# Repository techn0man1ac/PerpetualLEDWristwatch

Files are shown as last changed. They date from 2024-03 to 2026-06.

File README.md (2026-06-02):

UA_version_README
GB_version_README (https://github.com/techn0man1ac/PerpetualLEDWristwatch)

# 12 LED ATtiny "Perpetual" Wristwatch

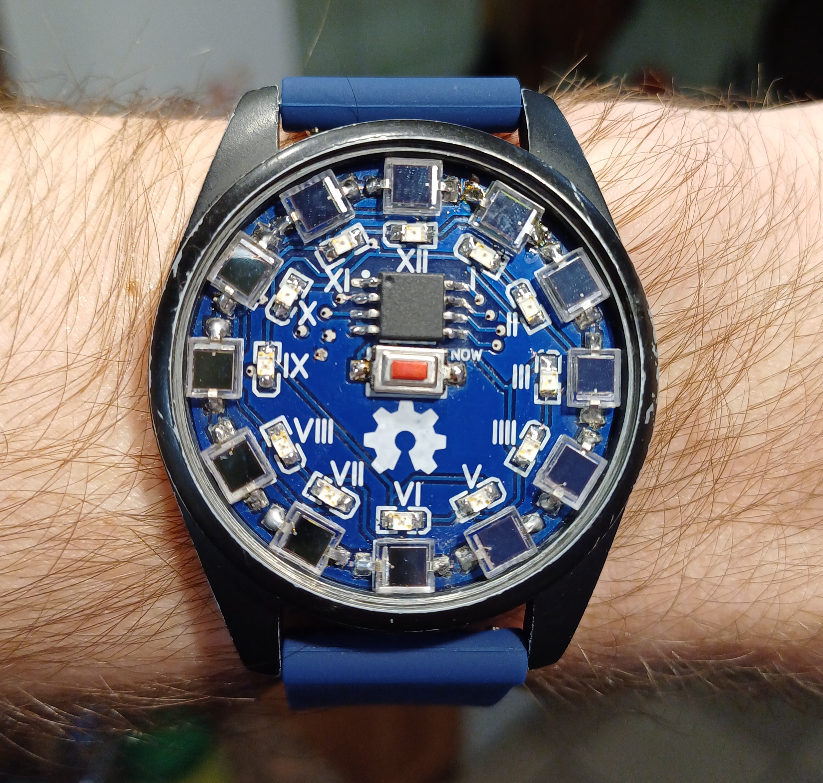
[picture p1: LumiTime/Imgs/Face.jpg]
Device_face


The simple and "Perpetual" WristWatch(project code name "LumiTime") with 12 red LEDs, it have LIR2430 Li-Ion battery and 12 solar cells, based on a simple Microchip microcontroller ATtiny13. It full open source(firmware and hardware).

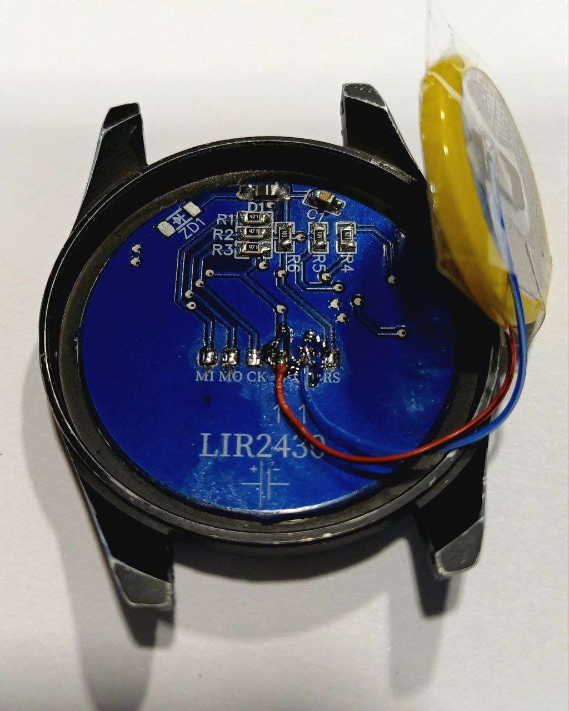
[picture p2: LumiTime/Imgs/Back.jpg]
PCB_back


# Video demonstration:

https://youtu.be/T3b3lKKN2u0

# How it's work?

Every 0.5 seconds, the processor wakes up (cycle iteration time is 100 microseconds), increments the millisecond variable, and quickly goes to sleep, the whole process consumes 3 to 5 µA:

https://youtu.be/rdMVb2fhGco

The wristwatch has a "NOW" button and 12 LEDs, if you press the button, the time is displayed on the LEDs according to the following algorithm - first the hours are displayed (1, 2, 3, 4, 5, 6, etc. ) and then the minutes are shown in step 5 minute(5, 10, 15, 20, 25, 30, and so on...), but the LED blinks as many times as you need to add to this number to get the time. 
For example, it is now 48 minutes, the LED 45 will light up and blink 3 times, that is, 45+3=48. Then CPU go back to sleep.

# How to set the time?

https://www.youtube.com/shorts/7TG0KjUsHnk

If you press the button and hold it, after 10 seconds the watch will start shifting the time by 5 minutes each display cycle, and this will continue until you release the button.

# 3D model PCB:

PCB face side:

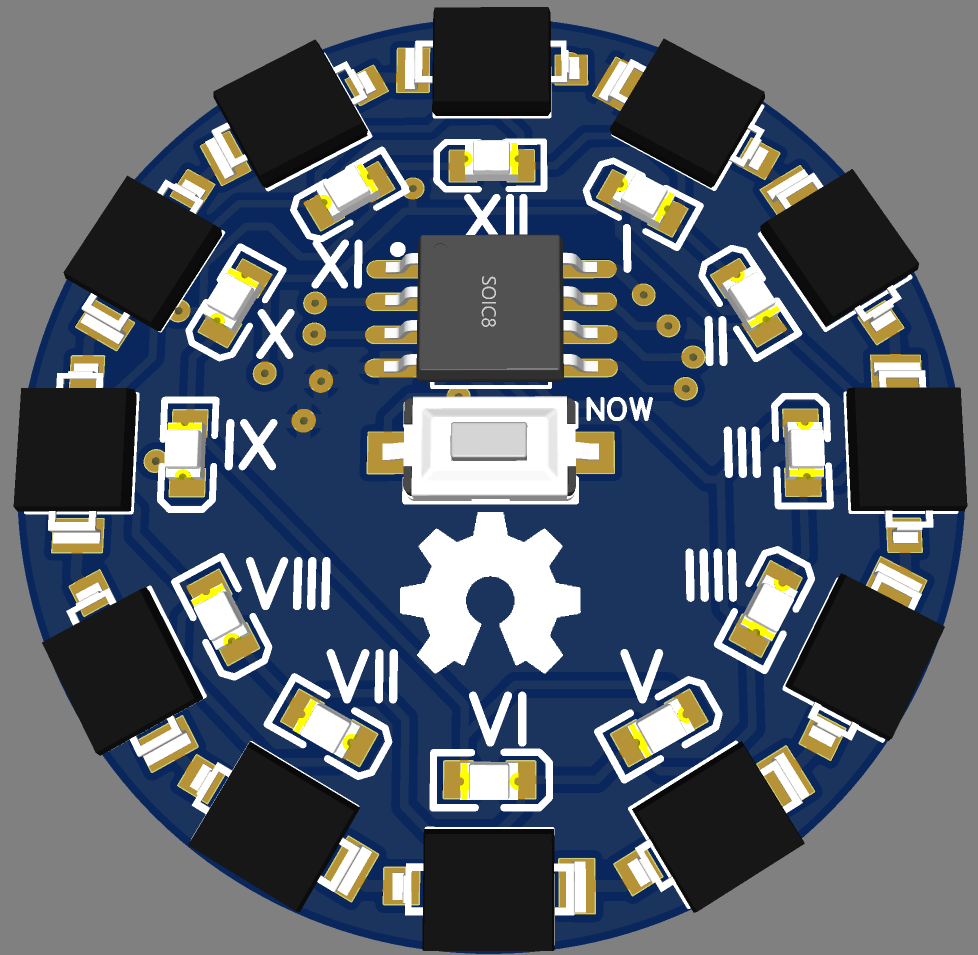
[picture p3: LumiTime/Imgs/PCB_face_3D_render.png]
PCB_Up_3D_Render


PCB back side:

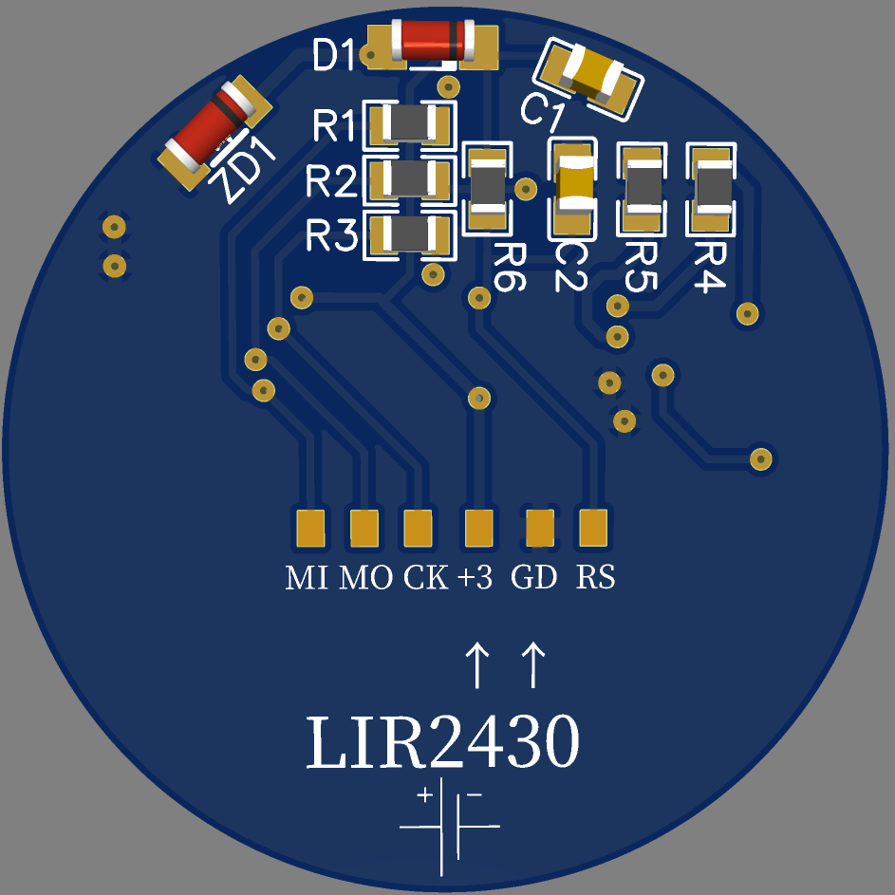
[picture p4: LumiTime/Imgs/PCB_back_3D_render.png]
PCB_Down_side_3D_Render


PCB have size 35 mm in the diameter:

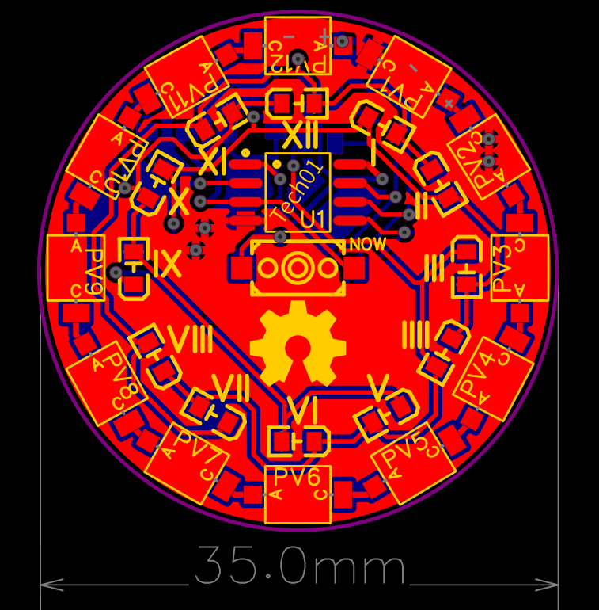
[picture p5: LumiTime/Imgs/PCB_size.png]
PCB_size


The thickness of the board is recommended to take 0.8mm otherwise it may not fit into the case.

# Gerber files and 3D model:

Files for fabrication:

https://github.com/techn0man1ac/PerpetualLEDWristwatch/tree/main/LumiTime/PCB

# PCB home page:

Fresh board project here:

https://oshwlab.com/raznie.podelki/attiny85binarywatches_copy

You can order a prototype for testing here(completely ready device without firmware):

https://www.pcbway.com/project/shareproject/_Perpetual_Wristwatch_d14e5fc4.html

# Schematic:

It's have simple schematic, for save pins I used Charlieplexing(35 components in total):

https://en.wikipedia.org/wiki/Charlieplexing

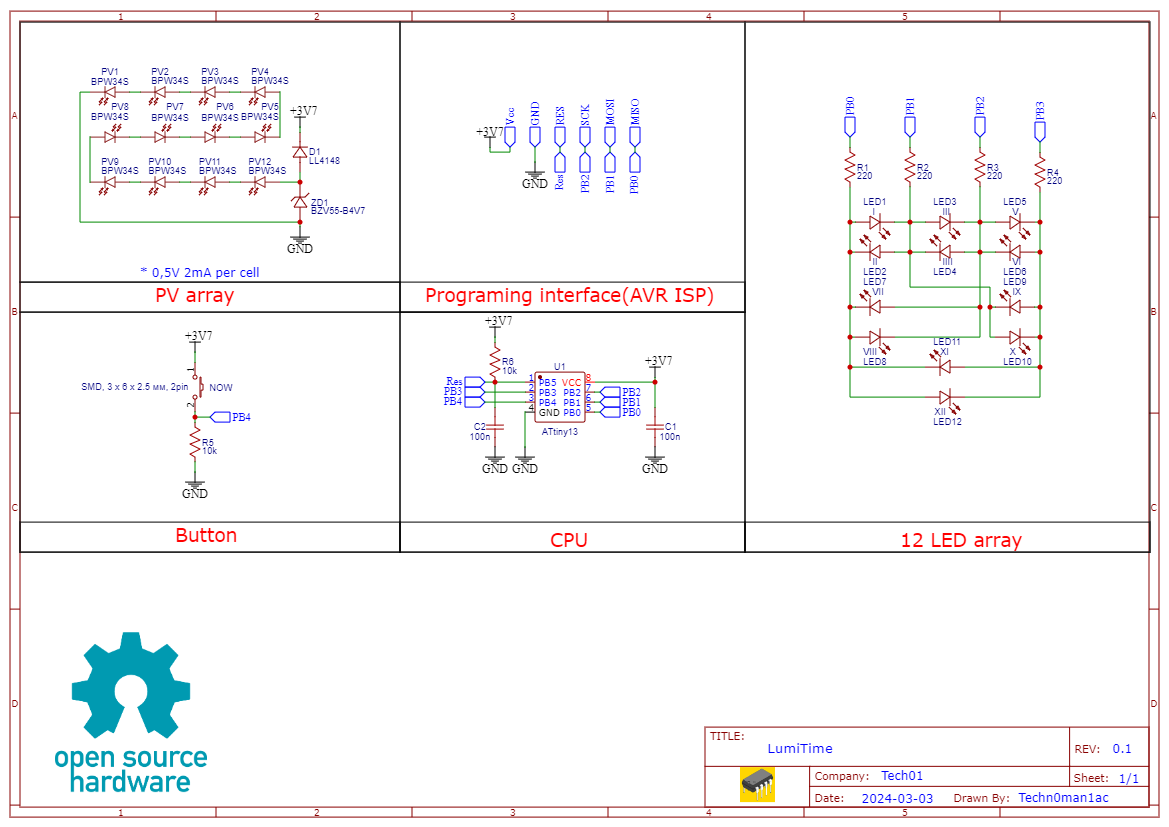
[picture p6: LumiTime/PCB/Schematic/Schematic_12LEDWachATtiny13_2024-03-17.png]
Schematic_Wristwatch


In this project i use for charging 12 light sensor BPW34S(PV array), on clear sun one cell make 0.5-0.6 V and ~2 mA, connect its in serial and make simply charging schematic - use 2 components, ZD1 to drop voltage 6 -> 4.7 V and make protection to leakage of current in solar panels in to diode D1 name LL4148(because it have little reverse current):

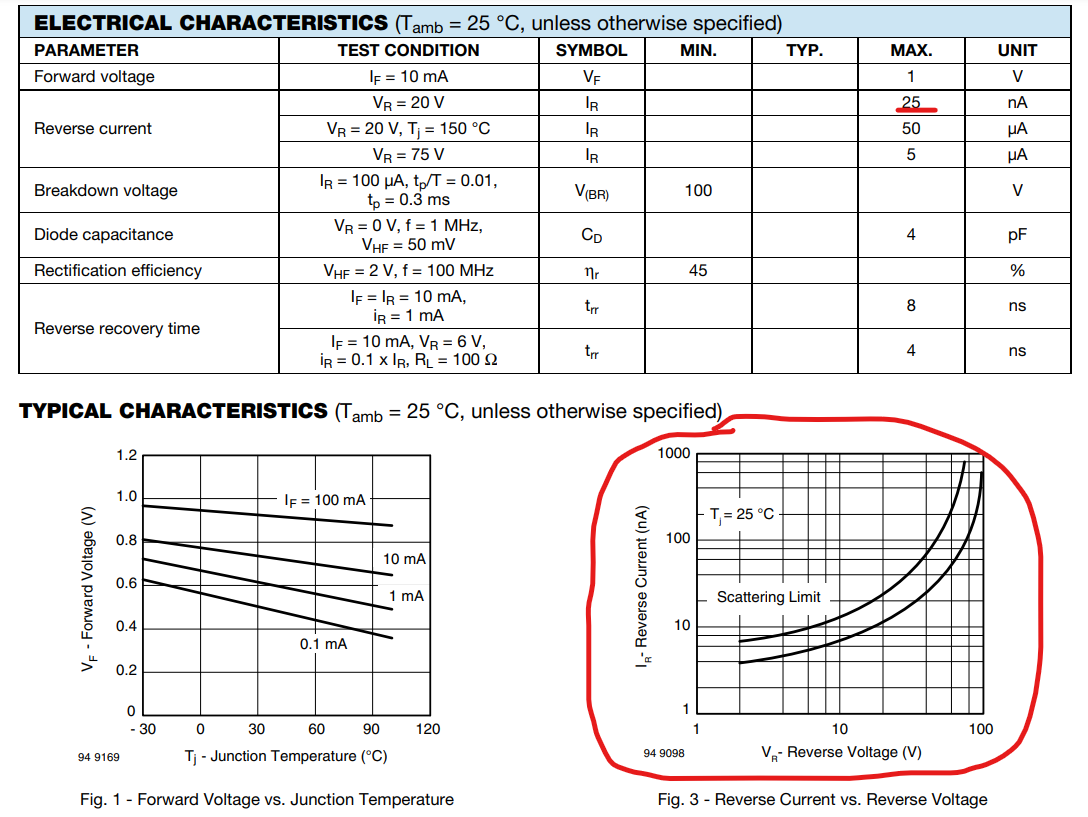
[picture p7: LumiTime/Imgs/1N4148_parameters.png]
1N4148_parameters


The diode add 0.7 volts drop(4.7-0.7=4.0V) and battery don't overcharge up to 4 V.

# How to flash ATtiny

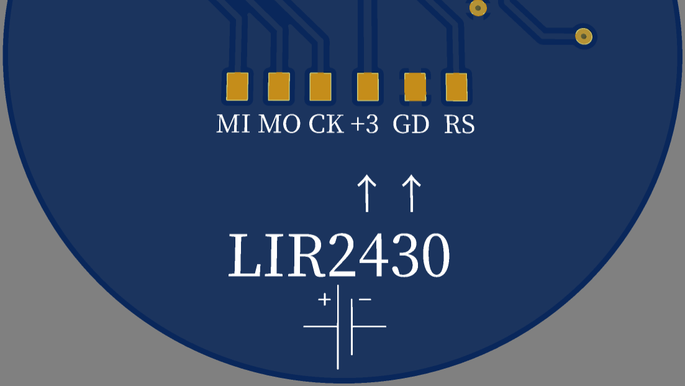
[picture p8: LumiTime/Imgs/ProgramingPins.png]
AVR ISP programmer pinout


Here is pinout for AVR ISP programmer - unsolder battery and power up 3V pins to programmer 5V, MI->MISO programer(Arduino digital Pin 11), MO->MOSI(digital Pin 12), CK->SCK(digital Pin 13) RS->Reset(digital Pin 10) and GD-> programmer GND. 

How to flash ATtiny13 with Arduino:

https://www.hackster.io/taunoerik/programming-attiny13-with-arduino-uno-07beba

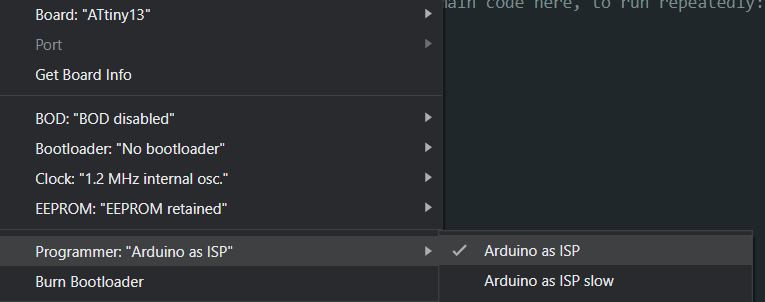
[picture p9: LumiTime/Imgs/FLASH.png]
FLASH


ATtiny13 core selections:

- Board: ATtiny 13

- BOD: BOD Disabled

- Clock: 1.2 MHz internal osc.

- Compiler LTO: Enable

- Port: (Your Arduino port)

- Programmer: Arduino as ISP

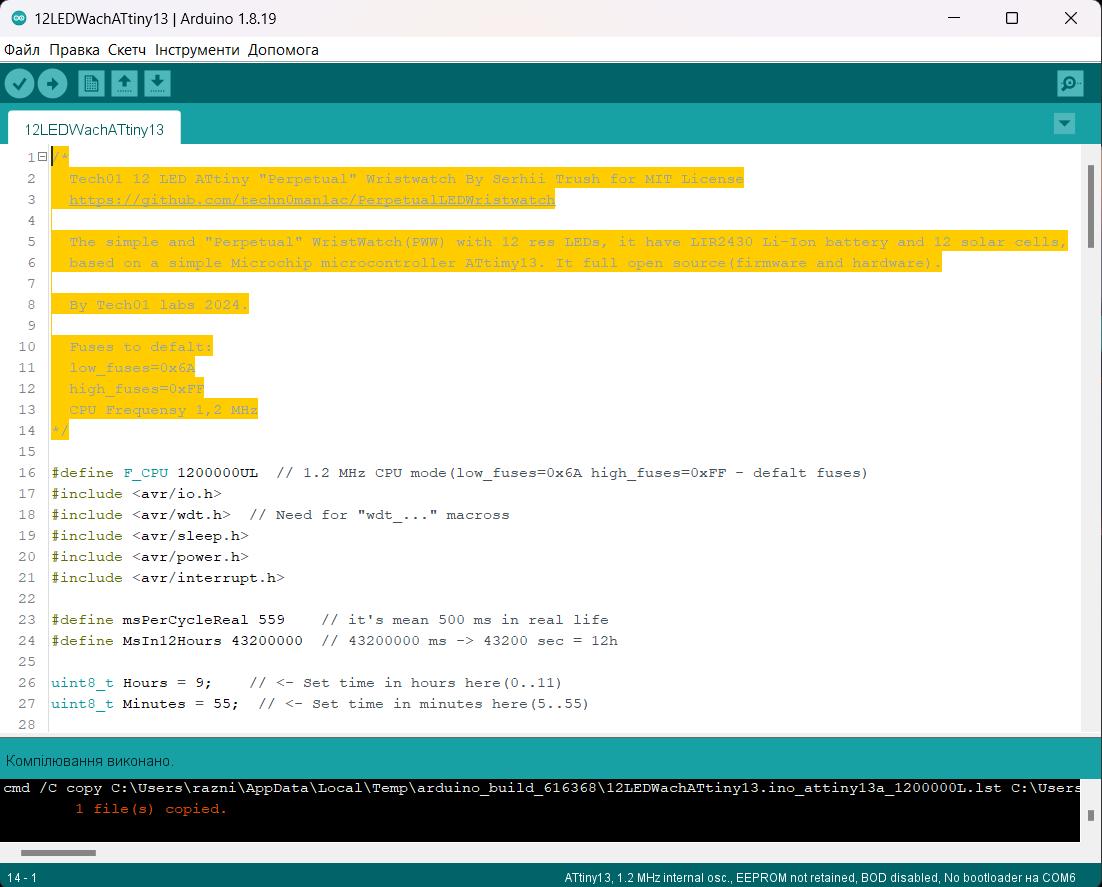
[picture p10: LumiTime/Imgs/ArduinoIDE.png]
Arduino IDE


Source code(for Arduino IDE - "12LEDWachATtiny13.ino") here:

https://github.com/techn0man1ac/PerpetualLEDWristwatch/tree/main/LumiTime/Code/12LEDWachATtiny13

The default time, which start the clock, set in the code, these are the 27 and 28 code lines.

This project full open source(PCB and code), so anyone can modernize it. But we must give credit to the previous project, without which there would be no "ATtiny13BinaryWatches":

https://github.com/techn0man1ac/ATtiny13BinaryWatches

# Power consumption

In standby mode (when the button is not pressed), the wristwatch consumes approximately 5 μA, the battery have capacity - 50 mAh, in time show mode watch consumes 2.5 mA, if you look at the time every day 6 times(0.25 per hour), the operating time is 1.5 seconds, using these data we can calculate battery life time. For example - calculator from Oregon Embedded:

https://oregonembedded.com/batterycalc.htm

We have ~year of work, of course, as the voltage drops, the consumption of the watch will also drop (for example - 2.7 V, the consumption is ~3 μA), therefore, the resulting lower value is the guaranteed uptime:

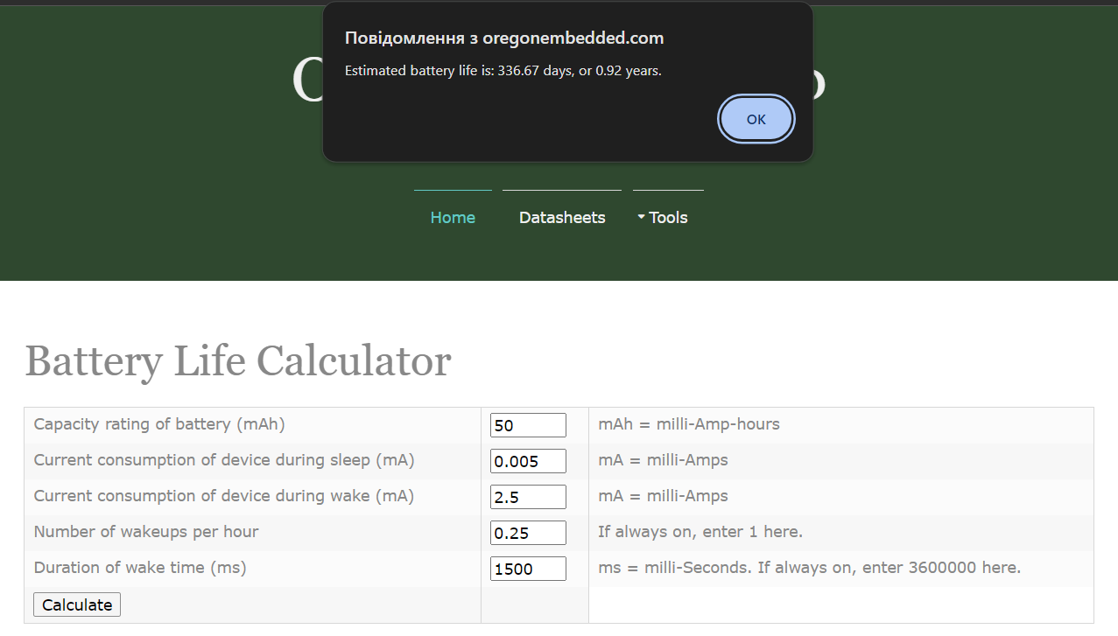
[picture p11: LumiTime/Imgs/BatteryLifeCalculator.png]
BatteryLifeCalculator


However, if you give the device 5-10 minutes a day of street light (for example, take it out of your sleeve), and the working time will immediately increase several times. Here in the video I show how the watch charges even in cloudy weather:

https://youtu.be/5vcrXjH7wVM

It is worth noting that LED bulbs, which are now very popular for indoor lighting, do not provide a sufficient level of light in the spectrum at which solar panels work, so charging is possible only very close LED lamp.

# Case

You can find the case files here:

https://github.com/techn0man1ac/PerpetualLEDWristwatch/tree/main/LumiTime/Case

Please note that the project is still under development and is subject to change.

# Our mission and vision

Mission:

"To develop a simply and eco-friendly watch that integrates innovative technologies with minimal components, ensuring energy efficiency is within reach for all.".

Vision:

"We aim to achieve a world where energy-saving technology is accessible to everyone, where our watch serves as a symbol of environmental stewardship and innovative solutions in energy efficiency."

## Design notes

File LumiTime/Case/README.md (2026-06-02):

Design based the case on a watch similar to my project:

https://www.thingiverse.com/thing:4037268

The only difference is that theirs has two buttons, while mine has just one.

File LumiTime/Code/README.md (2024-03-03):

  By Tech01 labs 2024.

  Fuses to defalt:
  
  low_fuses=0x6A
  
  high_fuses=0xFF
  
  CPU Frequensy 1,2 MHz

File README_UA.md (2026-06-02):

UA_version_README
GB_version_README (https://github.com/techn0man1ac/PerpetualLEDWristwatch)

# "Вічний" наручний годиник на 12-ти світлодіодах

Device_face

Простий та "вічний" наручний годиник з 12-ма світлодіодами(кодове ім'я проєкту "LumiTime"), має LIR2430 Li-Ion батарею та 12 мікро сонячних панелей, оснований на простому мікроконтролері від Microchip ATtiny13. Цей проєкт повністю open source(залізо та прошивка).

PCB_back

# Відео з демонстрацією:

https://youtu.be/T3b3lKKN2u0

# Як це працює?

Кожні 0.5 секунди процесор прокидається(час ітерації циклу 100 мікросекунд), інкрементує змінну мілісекунд, та швиденько засипає, весь цей процес забирає споживання від 3 до 5 мкА:

https://youtu.be/rdMVb2fhGco

Наручний годиник має кнопку "NOW" та 12 світлодіодів, якщо натиснути кнопку - показується час на світлодіодах згідно з наступним алгоритмом - спочатку показуються години(1, 2, 3, 4, 5, 6 і так далі...) і потім показуються хвилини з кроком в 5 хв(5, 10, 15, 20, 25, 30 і так далі...), але світлодіод блимає стількм разів, скільки треба додати до цього числа щоб отримати час, наприклад зараз 48 хвилин, загориться світлодіод 45 і проблимає 3 рази, тобто 45+3=48. Далі -> знову сон.

# Як виставити час?

https://www.youtube.com/shorts/7TG0KjUsHnk

Якщо натиснути кнопку і тримати її на протязі 10 секунд, час почне збільшуватись на 5 хв кожен цикл відображення доти, допоки кнопка не відпуститься.

# 3D рендер плати:

Лицьова сторона плати:

PCB_Up_3D_Render

Зворотня сторона плати:

PCB_Down_side_3D_Render

Плата має 35 мм в діаметрі:

PCB_size

Товщина плати має бути 0.8 мм, інакше просто не поміститься в корпус.

# Gerber файли та 3D модель:

Файли для виготовлення:

https://github.com/techn0man1ac/PerpetualLEDWristwatch/tree/main/LumiTime/PCB

# Сторінка плати:

Свіжа версія плати завжди тут:

https://oshwlab.com/raznie.podelki/attiny85binarywatches_copy

Замовити прототип для тестування можна ось тут(закінчений пристрій але без прошивки):

https://www.pcbway.com/project/shareproject/_Perpetual_Wristwatch_d14e5fc4.html

# Схемотехніка:

Пристрій має просту схемотехніку, для економії виходів мікроконтролера я використав Мультиплексування методом Чарлі(сумарно 35 компонентів):

https://en.wikipedia.org/wiki/Charlieplexing

Schematic_Wristwatch

В цьому проєкті, для заряджання, я використав 12 фотодіодів BPW34S(PV array), у сонячну погоду один елемент генерує 0.5-0.6 В і ~2 мА, з'єднав їх послідовно та зробив просту зарядну схему використовуючи 2 компоненти - стабілітрон ZD1 знижує напругу з 6 до 4.7 В та наявний захист від "витоку" струму в сонячні панелі з допомогою діоду D1 LL4148(саме цей має низький зворотній струм):

1N4148_parameters

Діод добавляє падіння напруги в 0.7(4.7-0.7=4.0 В), відповідно, акумулятор не перезарядиться більше 4 В.

# Як запрограмувати мікроконтролер ATtiny

AVR ISP programmer pinout

Ось розпіновка для підключення до AVR ISP програматора - відпаяйте батарею і запаяйте на ніжку 3V 5 Вольт з програматора, MI->MISO програматора(Arduino пін 11), MO->MOSI(пін 12), CK->SCK(пін 13) RS->Reset(пін 10) та GD-> земля програматора(GND).

Як запрограмувати ATtiny13 використовуючи Arduino:

https://www-hackster-io.translate.goog/taunoerik/programming-attiny13-with-arduino-uno-07beba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

FLASH

Параметри для ATtiny13:

- Плата: ATtiny 13

- BOD: BOD Disabled

- Частота: 1.2 MHz internal osc.

- Compiler LTO: Enable

- Порт: (Ваш Arduino порт)

- Програматор: Arduino as ISP

Arduino IDE

Вихідний код(для Arduino IDE - "12LEDWachATtiny13.ino") ось тут:

https://github.com/techn0man1ac/PerpetualLEDWristwatch/tree/main/LumiTime/Code/12LEDWachATtiny13

Час по замовчуванню, з якого стартує годинник задається в коді, це 27 та 28 стрічки.

Цей проєкт є повністю відкритим, як плата так і прошивка для мікроконтролера, тому його модернізувати може кожен. Але треба віддати належне попередньому проєкту, без якого цього б не існувало "Бінарний наручний годиник":

https://github.com/techn0man1ac/ATtiny13BinaryWatches

# Енергоспоживання

В режимі очікування(коли кнопка не натиснена) годинник споживає приблизно 5 мкА, ємність акумулятора 50 мА*год, під час роботи годинник споживає 2.5 мА, якщо дивитись час 6 разів на добу(0.25 разів на годину) час роботи 1.5 секунди, використовуючи ці дані можна порахувати на скільки вистачить батареї. Наприклад - калькулятором від Oregon Embedded:

https://oregonembedded.com/batterycalc.htm

Маємо майже рік роботи, звісно з падінням напруги буде падати і споживання годинника(при 2.7 В споживання вже 3 мкА), тому отримане нище значення, це гарантований час роботи:

BatteryLifeCalculator

Проте, варто лиш 5-10 хвилин на день потримати девайс на вуличному світлі(наприклад дістати його з рукава), і відразу термін роботи збильшиться в рази, ось на відео показую, як годинник заряджається навіть у похмуру погоду:

https://youtu.be/5vcrXjH7wVM

Варто зауважити, що світлодіодні лампочки, котрі зараз дуже популярні для кімнатного освітлення не дають достатній рівень світла в спектрі, при якому працюють сонячні панелі, тому зарядка можлива лиш в притул до LED лампи.

# Корпус

Файли корпусу можна знайти за посиланням:

https://github.com/techn0man1ac/PerpetualLEDWristwatch/tree/main/LumiTime/Case

Зверніть увагу, що проект ще перебуває на стадії розробки і може зазнавати змін.

# Місія та візія проєкту

Місія:

"Розробити простий і екологічно чистий годинник, який поєднує в собі інноваційні технології з мінімальною кількістю компонентів, гарантуючи, що енергоефективність доступна для всіх.".

Візія:

"Ми прагнемо створити світ, де енергозберігаючі технології будуть доступні кожному, де наш годинник буде символом піклування про навколишнє середовище та інноваційних рішень у сфері енергоефективності."

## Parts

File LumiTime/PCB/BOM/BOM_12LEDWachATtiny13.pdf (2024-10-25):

ID | Name | Designator | Footprint | Quantity | Manufacturer Part
1 100n | | C1,C2 | C0805 | 2 50V 100nF X7R ±10% 0805 Multilayer Ceramic Capacitors
2 LL4148 | | D1 | LL-34_L3.4-W1.5-RD | 1 LL4148 SOD80
3 LED1-LED12 | | I-XII | LED0805-RD_RED | 12 SMD Red LED 0805
4 SMD, 3 x 6 x 2.5 мм, 2pin | | NOW | KEY-SMD_2P-L6.2-W3.6-LS | 1 SMD, 3 x 6 x 2.5 мм, 2pin
5 BPW34S | | PV1,PV2,PV3,PV4,PV5,PV6,PV7,PV8,PV9,PV10,PV11,PV12SENSOR-TH_BPW34S-Z | | 12 BPW34S-Z
6 220 | | R1,R2,R3,R4 | R0805 | 4 ±5% 220Ω 0805 Chip Resistor
7 10k | | R5,R6 | R0805 | 2 ±5% 10kΩ 0805 Chip Resistor
8 ATtiny13 | | U1 | SOIC-8_L5.3-W5.3-P1.27-L | 1 ATTINY13A-SU
9 BZV55-B4V7 | | ZD1 | LL-34_L3.5-W1.5-RD | 1 BZV55-B4V7 SOD80

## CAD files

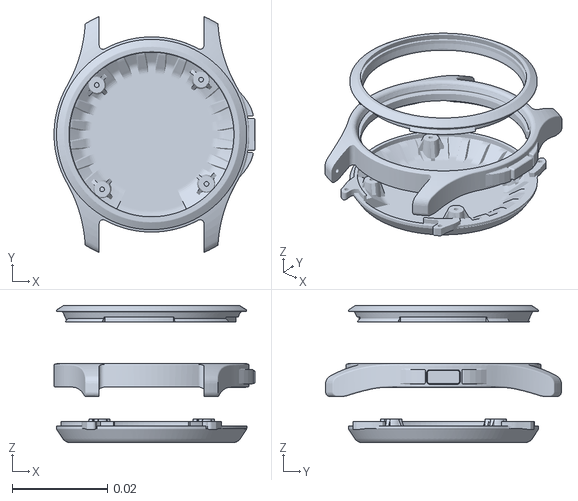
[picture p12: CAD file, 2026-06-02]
LumiTime/Case/Watch.stl
0.0422 x 0.0496 x 0.0289

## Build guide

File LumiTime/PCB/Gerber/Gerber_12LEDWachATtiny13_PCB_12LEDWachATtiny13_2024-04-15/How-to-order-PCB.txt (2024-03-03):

How to Order PCB

Please refer to:
https://docs.easyeda.com/en/PCB/Order-PCB

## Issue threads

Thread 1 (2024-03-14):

case?

alwaysmohawk, 2024-03-14:
Hi, cool project, found it on hackaday.

I didn't see any information on the case you used. Is it possible to share the source of your watch case, or give some tips on how to find a suitable case?

Thanks,

techn0man1ac, 2024-03-14:
Hi, thank's. I use case from old China wristwatch.
I still don't know how to do 3D modeling, so I didn't design the case, but used an already ready one.
Yes, I am open to all advice from your side

techn0man1ac, 2024-03-16:
> ...or give some tips on how to find a suitable case?

PCB have size 35 mm in the diameter,  search for cases from an old watch where the dial is 35 mm in diameter
The thickness of the PCB is recommended to take 0.8mm, because it will be very tight in the case with the battery.

voloved, 2024-11-04:
>  I use case from old China wristwatch

Do you know the exact model you used?

techn0man1ac, 2024-11-08:
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
No name brand

Closed 2025-01-16.

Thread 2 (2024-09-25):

Setting Time

edoxxx, 2024-09-25:
hello, very interesting project but would it be possible to develop the code to reset the hour and minutes by taking advantage of the button? because putting back the time would mean having a computer.

let me know.

techn0man1ac, 2024-10-12:
Hi @edoxxx yes, it's [done](https://github.com/techn0man1ac/PerpetualLEDWristwatch/commit/85db25f01018a77f09de6c6412757746059755f4).

Thank you for your request, at the moment I have reset the clock to the initial time if you press the button for more than 10 seconds.

You can test and provide feedback here.

techn0man1ac, 2024-10-17:
@edoxxx Yes, you can take a more advanced model - ATtiny85 where there is 8 times more flash memory. However, I plan to add  for ATtiny13 a time task (if you hold the button for more than 10 seconds, then the time will change every 1 second of holding the button up to 5 minutes) and so on until you release the button.

A watch case would be great, if you need some dimensions - write, I will measure everything.

edoxxx, 2024-10-17:
Wow if you could write this code, it would be great.

I was trying to create a code where the prolonged pressure takes you to the "hour menu" where with the single click you go on with the hours then you hold down for a long time and you go to the menu of minutes then you go back to the original operation.

But in my code there are too many variables to intercept the prolonged and single pressures that don't work well and if I try to add more code to fix I don't have any more space in the micro. 😂😮‍💨

techn0man1ac, 2024-10-18:
@edoxxx  I added a time setting (minutes) if you press and hold the button for more than 10 seconds, then the time will be added by 5 minutes per display cycle as long as the button is held.

techn0man1ac, 2024-10-19:
https://www.youtube.com/shorts/7TG0KjUsHnk

techn0man1ac, 2024-10-19:
https://www.youtube.com/shorts/7TG0KjUsHnk

edoxxx, 2024-10-19:
This is really amazing.
Now I think it's a really complete project.
Thank you very much!!

techn0man1ac, 2024-10-19:
Thank you @edoxxx

New feature and new bugs 🐞 🙂

It's just beginning, so a lot of work ahead 🚀

Closed 2024-10-22.

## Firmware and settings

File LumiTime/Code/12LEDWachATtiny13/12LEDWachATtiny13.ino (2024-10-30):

/*
  Tech01 12 LED ATtiny "Perpetual" Wristwatch By Serhii Trush with MIT License.
  https://github.com/techn0man1ac/PerpetualLEDWristwatch

  The simple and "Perpetual" WristWatch(project code name "LumiTime") with 12 red LEDs, it has LIR2430 Li-Ion battery and 12 solar cells,
  based on a simple Microchip microcontroller ATtiny13. It is fully open source (firmware and hardware).

  Sketch uses 1008 bytes (98%) of program storage space. Maximum is 1024 bytes.
  Global variables use 13 bytes (20%) of dynamic memory, leaving 51 bytes for local variables. Maximum is 64 bytes.

  By Tech01 labs 2024.
*/

#define F_CPU 1200000UL  // CPU frequency set to 1.2 MHz mode(low_fuses=0x6A high_fuses=0xFF - defalt fuses)
#include <avr/io.h>      // AVR I/O library for ATtiny13
#include <avr/wdt.h>     // Watchdog Timer library
#include <avr/sleep.h>   // Sleep mode library
#include <avr/power.h>   // Power management library
#include <avr/interrupt.h>  // Interrupt library

// Constants for time calculations
#define msPerCycleReal 560    // Real cycle duration in milliseconds (approximately 500ms)
#define MsIn12Hours 43200000  // Total milliseconds in 12 hours
#define ButtonPin PINB4       // PB4 is the button pin
#define TimeSetDalay 40       // TimeSetDalay / 4 = how many seconds need press the button to time set mode

// Global variables to store time and mode states
uint8_t Hours = 9;            // Default hour setting (0..11)
uint8_t Minutes = 18;         // Default minute setting (5..55)
volatile uint8_t InterruptWDT = 0; // Watchdog timer interrupt flag
volatile uint32_t MilliSeconds = 0;   // Milliseconds since the start of the current cycle
uint8_t FiveMinutesDiscrete = 0;  // Discretized minutes in steps of five (5,10..55)
uint8_t MinutesRemainder = 0;   // Remaining minutes after discretization (0..4)
uint8_t MinutesOnLED = 0;     // LED index for displaying time
uint8_t Mode = 0;             // Current mode state
uint8_t NextMode = 0;         // Next mode to transition into
uint8_t ButtonPressCount = 0; // Count of button presses

// Function prototypes for readability and organization
void initHardware();
uint8_t ButtonPress();        // Check if the button is pressed
uint8_t ShowTime(uint8_t);    // Display time on LEDs based on current mode
void ledOn(uint8_t);          // Turn on a specific LED (not used in this code)
void Up5Minutes();            // Increment time by 5 minutes
void TimeToMs();              // Convert hours and minutes to milliseconds

// Watchdog Timer interrupt service routine
ISR(WDT_vect) {
  InterruptWDT = 1;         // Set the watchdog timer interrupt flag
  WDTCR |= (1 << WDTIE);    // Re-enable watchdog interrupt after handling
}

int main() {
  initHardware();           // Initialize hardware components
  TimeToMs();               // Calculate default time in milliseconds
  sei();                    // Enable global interrupts
  set_sleep_mode(SLEEP_MODE_PWR_DOWN);  // Set sleep mode to power down

  while (1) {               // Main loop
    if (InterruptWDT == 1) {
      InterruptWDT = 0;  // Clear the watchdog timer interrupt flag
      uint8_t Button = ButtonPress();  // Check button state
      MilliSeconds += msPerCycleReal;          // Increment time by cycle duration

      if (MilliSeconds >= MsIn12Hours) {       // Handle overflow after 12 hours
        MilliSeconds -= MsIn12Hours;
      }

      if (Button || Mode > 0) {
        Mode = ShowTime(Mode);        // Display current time on LEDs
        ButtonPressCount += 1;

        if (ButtonPressCount > TimeSetDalay && Mode == 0) { // Increment time by 5 minutes after long press
          ButtonPressCount = TimeSetDalay; // Overflow protect
          Up5Minutes();
        }
      } else {
        ButtonPressCount = 0;         // Reset button press count when not in use
      }

    }
    sleep_enable();                       // Enable sleep mode
    sleep_cpu();                          // Enter sleep mode
  }
  return 0;
}

void initHardware() {
  ADCSRA &= ~(1 << ADEN);   // Disable Analog-to-Digital Converter (ADC)
  ACSR = (1 << ACD);        // Disable analog comparator
  DDRB = 0b00000;           // Set Port B as input
  wdt_reset();              // Reset watchdog timer
  wdt_enable(WDTO_500MS);   // Enable watchdog timer to trigger every 500ms
  WDTCR |= (1 << WDTIE);    // Enable watchdog interrupt
}

uint8_t ButtonPress() {
  return PINB & (1 << ButtonPin);  // Check if the button is pressed
}

uint8_t ShowTime(uint8_t currState) {
  uint8_t LEDValue = 0;
  switch (currState) {  // State machine for displaying time on LEDs
    case 0:
      if (!MilliSeconds) {  // Handle division by zero
        Hours = 0;
        Minutes = 0;
        FiveMinutesDiscrete = 0;
        MinutesRemainder = 0;
      } else {
        Hours = MilliSeconds / 3600000;          // Calculate hours from milliseconds
        Minutes = (MilliSeconds / 60000) % 60;   // Calculate minutes from milliseconds
        FiveMinutesDiscrete = (Minutes / 5) * 5;  // Discretize minutes to nearest five
        MinutesOnLED = FiveMinutesDiscrete / 5;
        MinutesRemainder = Minutes - FiveMinutesDiscrete;
      }

      LEDValue = Hours;
      currState = 2;  // No LEDs on
      NextMode = 1;   // Transition to showing minutes
      break;

    case 1:
      if (ButtonPressCount > TimeSetDalay) { // Time setup mode
        MinutesRemainder = 0;
        MinutesOnLED += 1; // We have step +5 minutes
      }

      LEDValue = MinutesOnLED;  // Display discretized minutes

      if (MinutesRemainder > 1) {
        MinutesRemainder -= 1;
        currState = 2;
        NextMode = 1;
      } else {
        MinutesRemainder = 0;
        currState = 2;
        NextMode = 0;  // Transition to no LEDs on
      }
      break;

    case 2:
      LEDValue = 13;   // Turn off all LEDs
      currState = NextMode;
      break;

    default:
      return 0;  // Invalid state
  }

  DisplayOnLED(LEDValue);  // Set Port B to display the current time on LEDs
  return currState;
}

void DisplayOnLED(uint8_t led) {  // Charlieplexing logic for LED display
  switch (led) {
    case 0: DDRB = 0b1001; PORTB = 0b0001; break;
    case 1: DDRB = 0b0011; PORTB = 0b0001; break;
    case 2: DDRB = 0b0011; PORTB = 0b0010; break;
    case 3: DDRB = 0b0110; PORTB = 0b0010; break;
    case 4: DDRB = 0b0110; PORTB = 0b0100; break;
    case 5: DDRB = 0b1100; PORTB = 0b0100; break;
    case 6: DDRB = 0b1100; PORTB = 0b1000; break;
    case 7: DDRB = 0b0101; PORTB = 0b0100; break;
    case 8: DDRB = 0b0101; PORTB = 0b0001; break;
    case 9: DDRB = 0b1010; PORTB = 0b1000; break;
    case 10: DDRB = 0b1010; PORTB = 0b0010; break;
    case 11: DDRB = 0b1001; PORTB = 0b1000; break;
    case 12: DDRB = 0b1001; PORTB = 0b0001; break; // Same as case 0
    case 13: DDRB = 0b0000; PORTB = 0b0000; break; // Turn off all LEDs
  }
}

void Up5Minutes() {
  Minutes = FiveMinutesDiscrete;
  TimeToMs();
  MilliSeconds += 300000;
}

void TimeToMs() {
  MilliSeconds = Hours * 3600000 + Minutes * 60000;  // Convert hours and minutes to total milliseconds
}

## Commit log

2024-03-03 Change #003
    Add project files
    [Drill_PTH_Through.DRL, Drill_PTH_Through_Via.DRL, Gerber_BoardOutlineLayer.GKO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]
2024-03-03 Change #003
    Add project files V2
    [Drill_PTH_Through.DRL, Drill_PTH_Through_Via.DRL, Gerber_BoardOutlineLayer.GKO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]
2024-03-03 Change #004
    Add pcb size picture
2024-03-03 Change #005
    Add device photos
2024-03-03 Change #006
    Add some 1N4148 diode parameters
2024-03-03 Change #008
    Add Arduino IDE screen
2024-03-03 Change #010
    Add new files
    [Drill_PTH_Through.DRL, Drill_PTH_Through_Via.DRL, Gerber_BoardOutlineLayer.GKO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]
2024-03-04 Change #012
    Fixed some display bugs
    [12LEDWachATtiny13.ino]
2024-03-05 Change #014
    Add photos device in case
2024-03-05 Change #015
    Add PCB link
2024-03-07 Change#018
    Add battery doc.
2024-03-09 Change#023
    Add button name
2024-03-11 Change#024
    Add BOM-file
    [BOM_12LEDWachATtiny13.xlsx]
2024-03-17 Change #027
    Добавляю реадмі для Української мови
2024-03-17 Change #028
    Добавив повний опис на Українській мові
2024-03-17 Change #031
    Добавив вибір мови
2024-03-17 Change #032
    Add project code name "LumiTime"
    [BOM_12LEDWachATtiny13.xlsx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]
2024-03-17 Change #035
    Добавив кодове ім'я для проєкту - "LumiTime"
2024-03-17 Change #035
    Добавив кодове ім'я проєкту "LumiTime"
2024-03-24 Change #036
    Add screen calculate battery life from:
    https://oregonembedded.com/batterycalc.htm
2024-03-24 Change#037
    Добавив кілька слів про енергоспоживання
2024-03-24 Change#038
    Add some words about Power consumption
2024-03-24 Change#037
    Добавив про 3 рази на годину
2024-03-24 Change#039
    Дописав про те, як задавати час в коді
2024-03-24 Change#042
    Не 3 рази на добу а 6
2024-04-06 Change#046
    Добавив посилання де купити прототип для участі в тестуванні
2024-04-06 Change#046
    "You can order a prototype for testing here"
2024-04-06 Change#046
    Add device order
2024-04-06 Change#046
    Добавив посилання на замовлення закінченого пристрою(без прошивки)
2024-04-15 Change#047
    Fresh GERBER files(i fix wrong anode and cathode sides of the photodiodes)
    [Drill_PTH_Through.DRL, Drill_PTH_Through_Via.DRL, Gerber_BoardOutlineLayer.GKO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]
2024-04-15 Change#048
    PCB render update(fixed wrong photodiodes position)
2024-04-15 Change#052
    Update BOM, ATtiny13 SSU -> ATtiny13 SU
    [BOM_12LEDWachATtiny13.xlsx]
2024-10-12 Change#053
    I add CPU reset feature. Press button 10 seconds and clock was reset to start settings.
    [12LEDWachATtiny13.ino]
2024-10-18 Change#054
    I added a time setting (minutes) if you press and hold the button for more than 10 seconds, then the time will be added by 5 minutes per display cycle as long as the button is held.
2024-10-18 Change#056
    Добавив опис процедури налаштування часу в годиннику.
2024-10-18 Change#057
    Change R1-R4 to 220 Ohm for a brighter shine of LEDs
2024-10-18 Change#058
    Change R1-R4 down to 220 Ohm.
2024-10-19 Change#057
    Добавив посилання на відео з демонстрацією задання часу для годинника
2024-10-25 Change#059
    Delete BOM catalog
    [BOM_12LEDWachATtiny13.xlsx]
2024-10-25 Change#060
    Update BOM files, R1-R4 change 470->220 Ohm.
    [BOM_12LEDWachATtiny13.xlsx]
2024-10-25 Change#061
    Fixed time set bugs
    [12LEDWachATtiny13.ino]
2024-10-29 Change#063
    Moved the main work from the interrupt vector to the main loop + renamed some variables for better understanding.
2024-10-30 Change#065
    Добавив опис яким чином виводиться час з точністю до хвилини.
2024-10-30 Change#066
    I fixed a few bugs, the first one was related to the time setting, when the actual time was 5 minutes behind the one set, and the second one was an overflow of the pressed button counter.
    [12LEDWachATtiny13.ino]
2026-06-02 Change#068
    Add case STL file.
    [Watch.stl]
2026-06-02 Change#069
    I have added information about the files used to create the watch case.
